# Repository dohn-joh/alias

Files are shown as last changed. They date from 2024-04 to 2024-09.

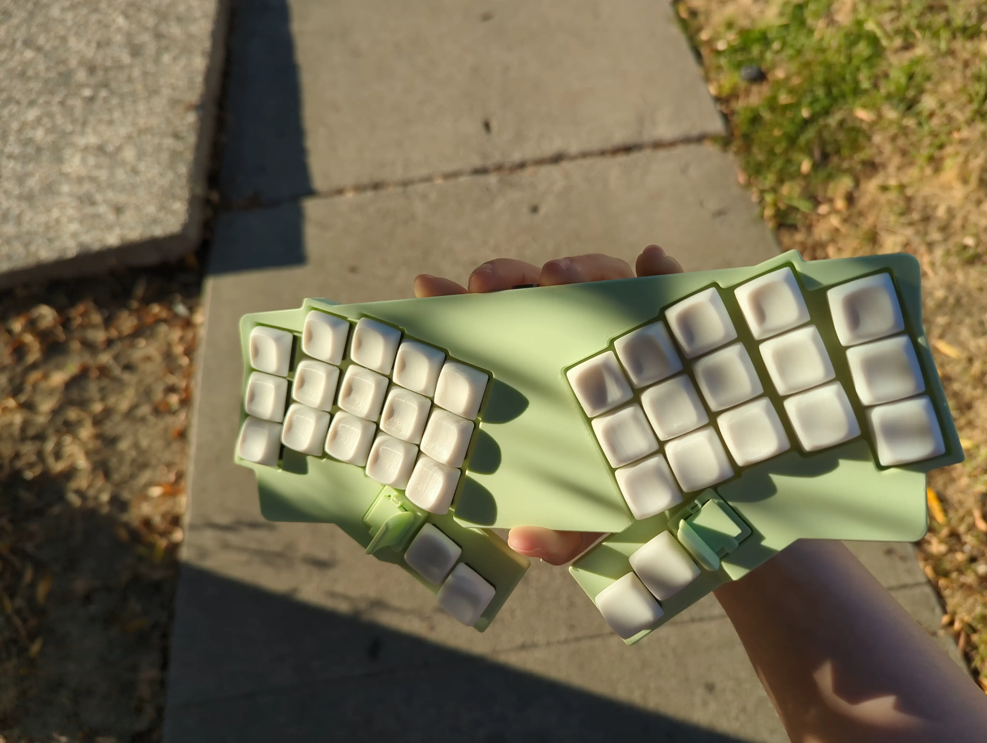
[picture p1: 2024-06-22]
photos/rotate.webp

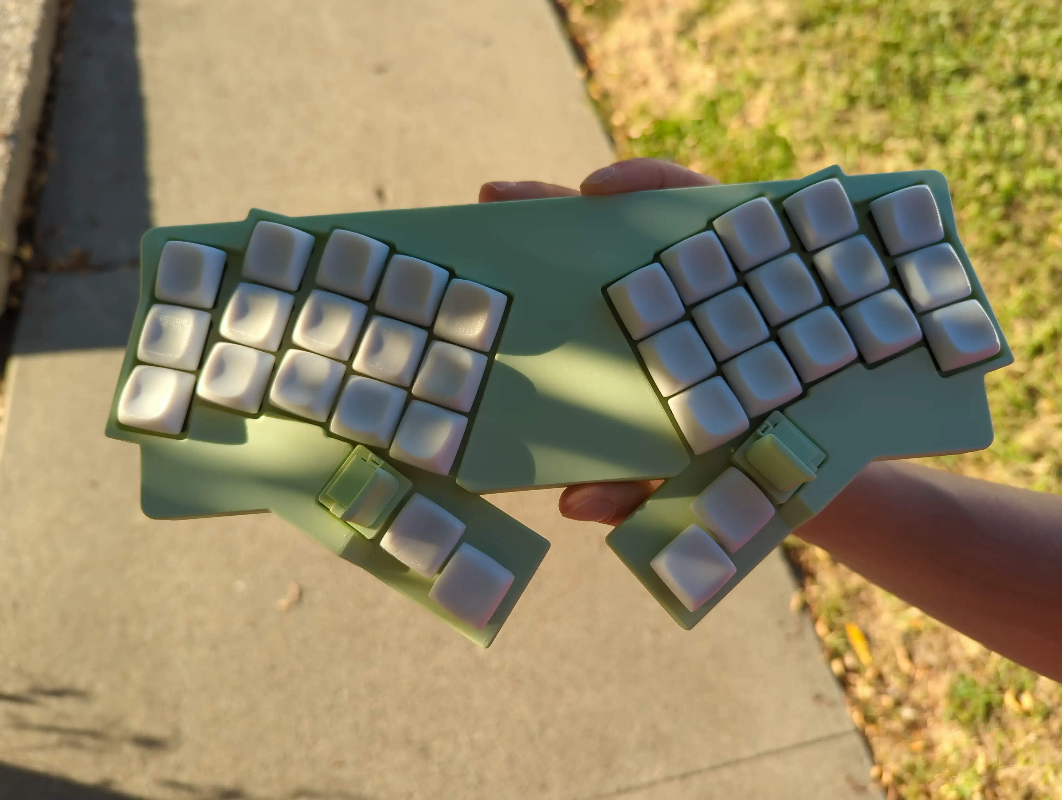
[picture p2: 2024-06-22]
photos/wave.webp

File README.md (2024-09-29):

# Alias

front
back
detail

## Features
- Custom 3D printed keycaps
  - [Lever keycaps](https://github.com/dohn-joh/keycaps)
  - [Low profile DES variant](https://github.com/dohn-joh/PseudoMakeMeKeyCapProfiles)
- Choc v1 and v2 compatible hotswap
- [Wireless dongle](https://github.com/dohn-joh/dongle-zmk)
- PCB generated in [ergogen](https://github.com/ergogen/ergogen)

## Compatibility/Disclaimer
Everything in this repo has been tested. Even so, use these files at your own risk. 
If you decide to have the pcb fabbed, 1.2mm pcb thickness is recommended. Higher thicknesses are still compatible but add height to the case.

- **Status of keycap compatibility**: only keycaps that are <=17.85mm wide and <=18mm deep are supported
- **Status of bottom case**: ~~cutouts are currently only compatible with choc v2 with the exception of the lever keys, which have cutouts that support both choc v1 and v2~~ fully compatible with both choc v1 and v2

## Parts
|Part: Model#|Link|
|-|-|
|Microcontroller: Supermini NRF52840 (or nice!nano)||
|Battery: 301230 with molex pico ezmate connector||
|Battery connector: molex pico ezmate 1x02||
|Power button: PCM12SMTR||
|Reset button: SKHLLCA010||
|Choc v1 or v2 switches x 36||
|Kailh Choc PG1350 Hot Swap Sockets x 36||
|Keycaps||
|Magnetic USB connector (optional): Netdot Gen10||

## Thanks
These people and many more helped make this keyboard possible. Yall are legends.
```
MrZealot
Pseudoku
petejohanson
caksoylar(bravekarma)
jcmkk3
ceoloide
infused-kim
Flatfootfox
sadekbaroudi
zzeneg
joelspadin
wolfwood
claussen
Geist
rmwphd(atinyzubat)
fish
Araxia
honorless
elkepenin
```

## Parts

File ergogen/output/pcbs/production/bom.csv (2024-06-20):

Designator | Footprint | Quantity | Value | LCSC Part #
CONN1 | conn_molex_pico_ezmate_1x02 | 1
D1, D10, D11, D12, D13, D14, D15, D16, D17, D18, D19, D2, D20, D21, D22, D23, D24, D25, D26, D27, D28, D29, D3, D30, D31, D32, D33, D34, D35, D36, D4, D5, D6, D7, D8, D9 | ComboDiode | 36
H1, H10, H11, H12, H13, H14, H15, H2, H3, H4, H5, H6, H7, H8, H9 | mounting_hole | 15
MCU1 | ProMicro | 1
PAD1 | pads | 1
S37 | SKHLLCA010 | 1 | SKHLLCA010
SW1 | power_switch | 1

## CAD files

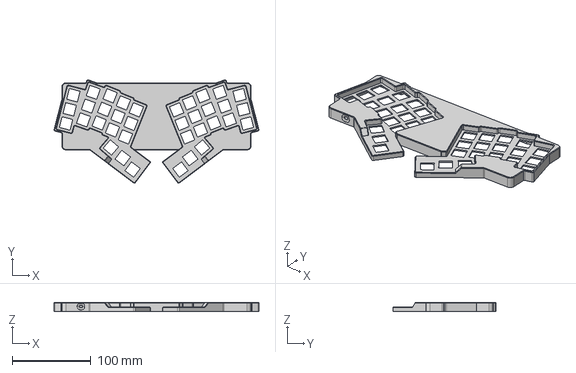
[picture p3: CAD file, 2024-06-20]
case/case_top.step
259.9 x 131.2 x 11.7 mm

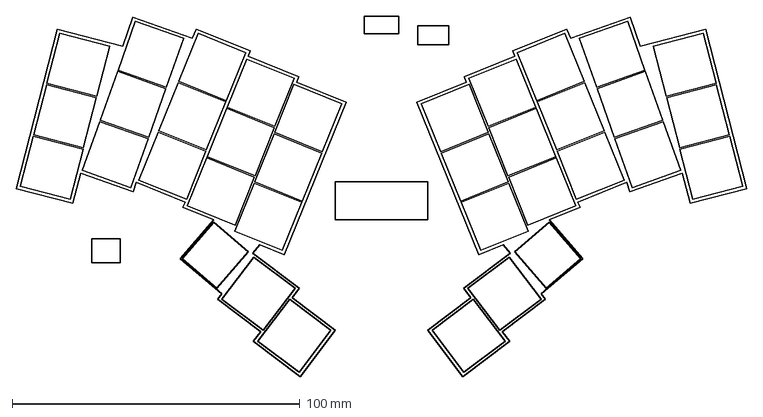
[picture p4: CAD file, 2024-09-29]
ergogen/output/outlines/preview.dxf
254.0 x 125.2 mm

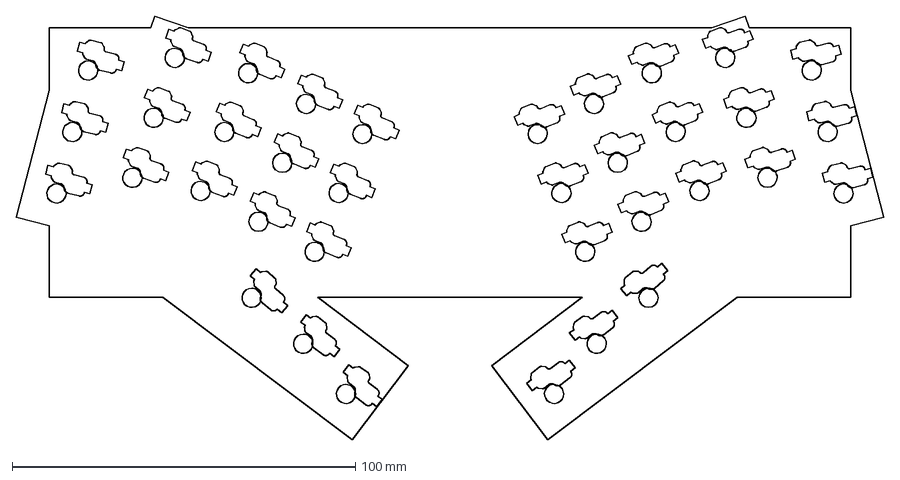
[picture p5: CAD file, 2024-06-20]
ergogen/output/pcbs/case_bottom-Edge_Cuts.dxf
252.6 x 123.5 mm

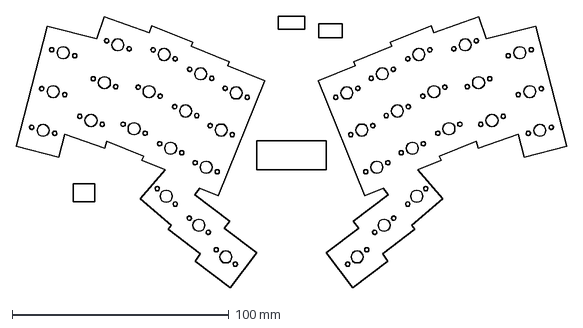
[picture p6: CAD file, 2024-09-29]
ergogen/output/outlines/case_bottom.dxf
254.0 x 125.2 mm

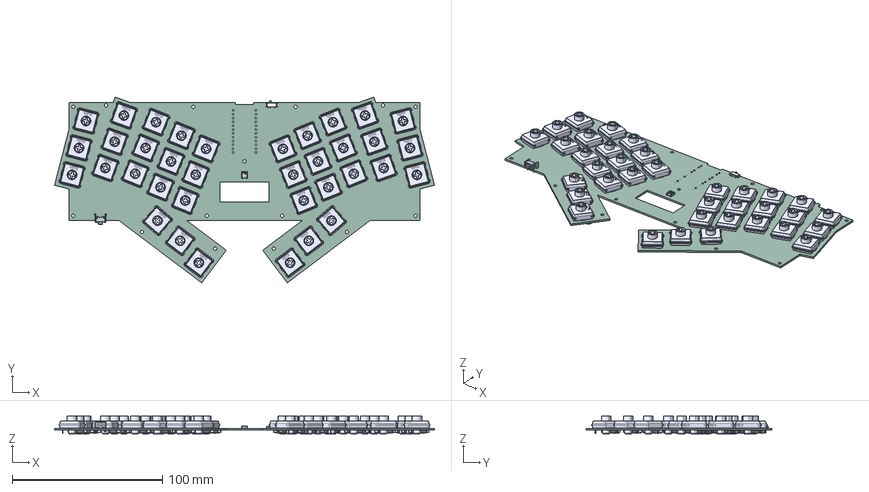
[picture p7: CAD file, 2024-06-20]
ergogen/output/pcbs/Alias.step
252.6 x 123.5 x 11.9 mm
781710002wbm000_01
PCM12SMTR
SKHLLC
Kailh_PG1352 x 36
PG1350 x 36
Alias_render_PCB

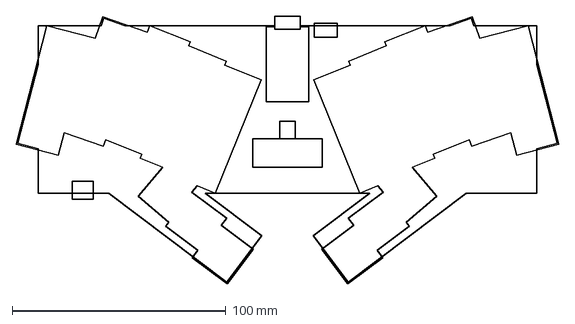
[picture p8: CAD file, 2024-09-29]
ergogen/output/outlines/pcb.dxf
254.0 x 125.2 mm

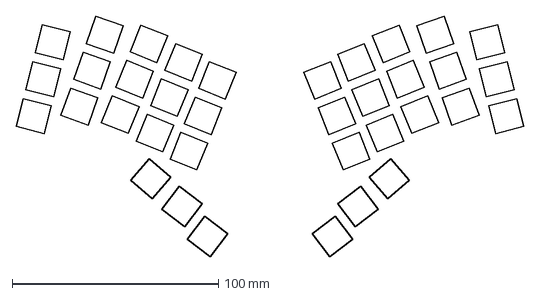
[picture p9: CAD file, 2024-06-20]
ergogen/output/outlines/switch_cutouts.dxf
246.3 x 116.6 mm

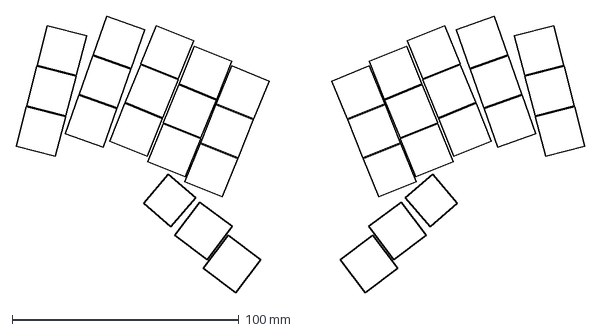
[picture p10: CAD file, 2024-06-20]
ergogen/output/outlines/keycaps.dxf
251.0 x 122.1 mm

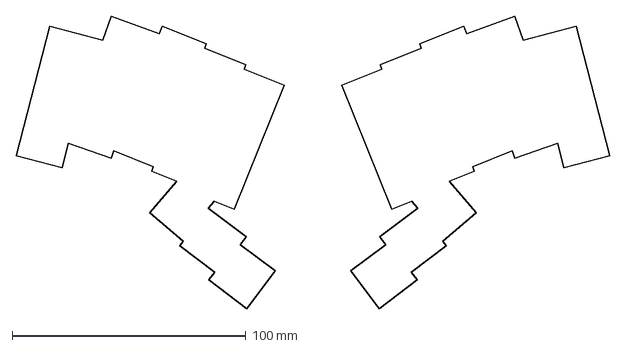
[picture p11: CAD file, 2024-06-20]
ergogen/output/outlines/key_walls.dxf
254.0 x 125.0 mm

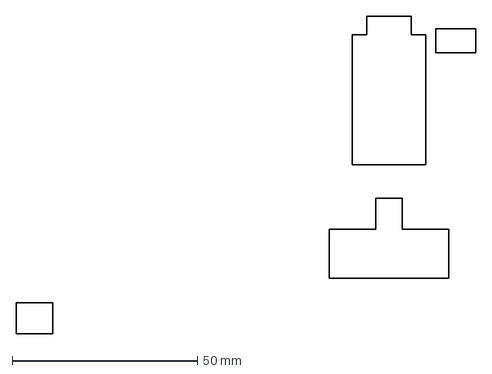
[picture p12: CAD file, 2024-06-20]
ergogen/output/outlines/case_cutouts.dxf
124.1 x 85.7 mm

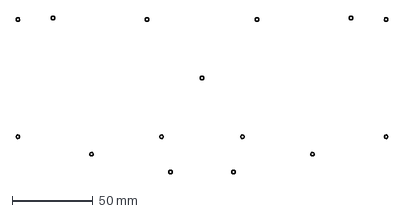
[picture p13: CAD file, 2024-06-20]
ergogen/output/outlines/screws.dxf
229.7 x 97.4 mm

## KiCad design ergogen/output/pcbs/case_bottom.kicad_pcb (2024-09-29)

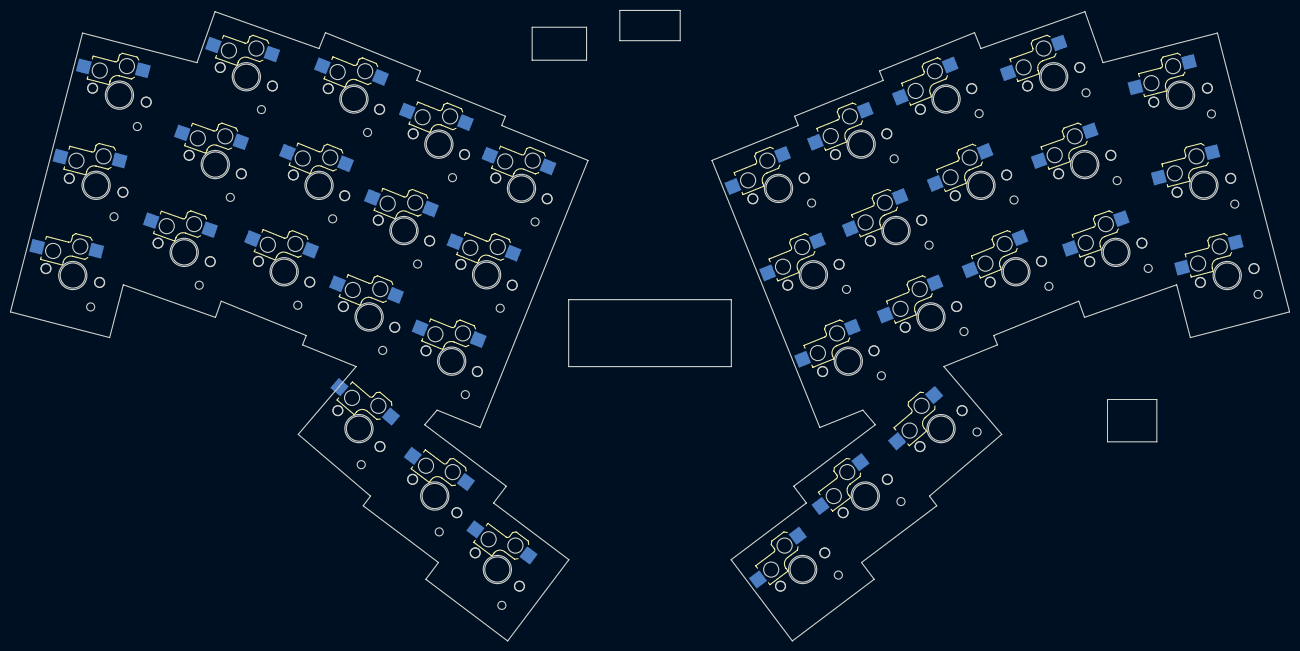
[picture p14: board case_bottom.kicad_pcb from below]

Board: 2 copper layers, 254.0 x 125.2 mm, 36 parts (36 on the bottom side), 5 nets, no tracks yet.

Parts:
S1, S2, S3, S4, S5, S6, S7, S8, S9, S10, S11, S12, S13, S14, S15, S16, S17, S18, S19, S20, S21, S22, S23, S24, S25, S26, S27, S28, S29, S30, S31, S32, S33, S34, S35, S36: switch_choc_v1_v2

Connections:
C0: S1.1, S2.1, S3.1, S16.1, S17.1, S18.1
C1: S4.1, S5.1, S6.1, S19.1, S20.1, S21.1
C2: S7.1, S8.1, S9.1, S22.1, S23.1, S24.1, S31.1, S34.1
C3: S10.1, S11.1, S12.1, S25.1, S26.1, S27.1, S32.1, S35.1
C4: S13.1, S14.1, S15.1, S28.1, S29.1, S30.1, S33.1, S36.1

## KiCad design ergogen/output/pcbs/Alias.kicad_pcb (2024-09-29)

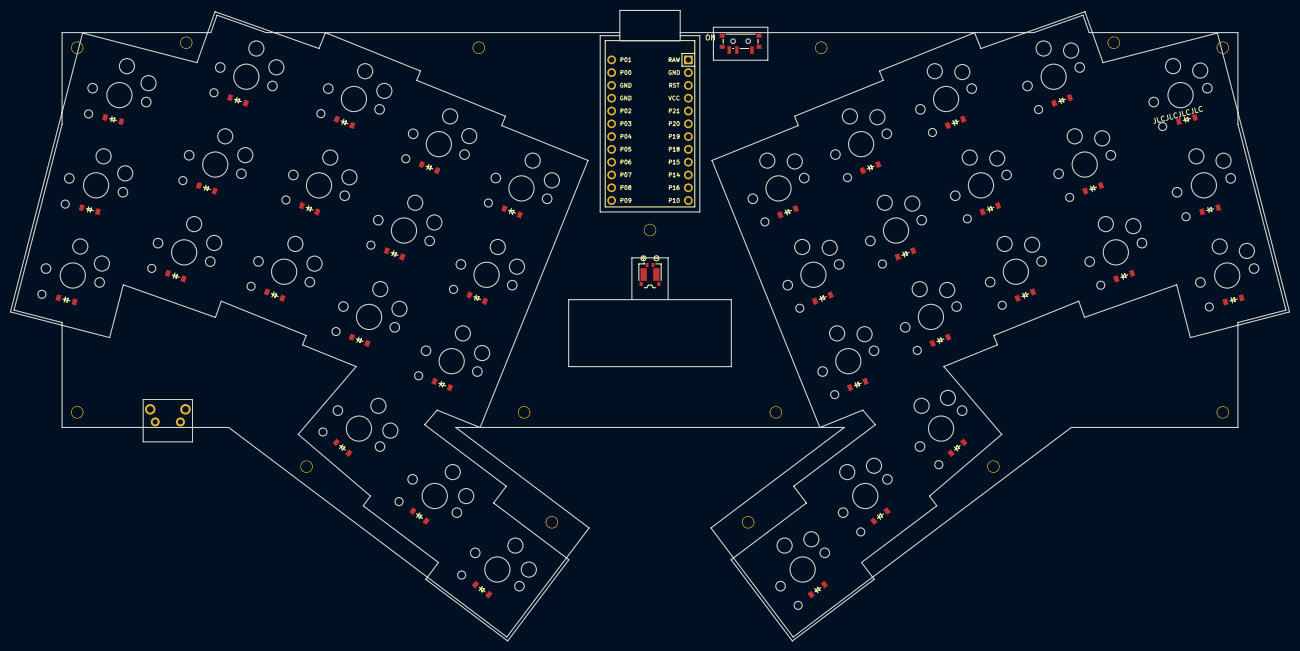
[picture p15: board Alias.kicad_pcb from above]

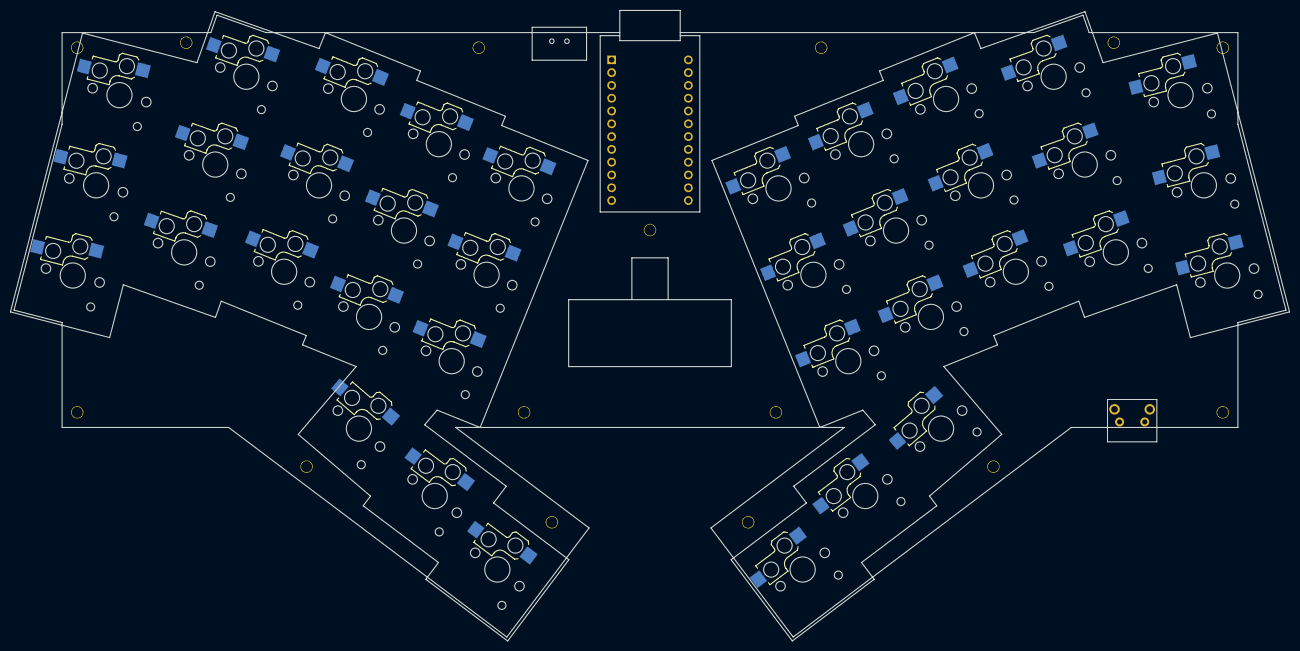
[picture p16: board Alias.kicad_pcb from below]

Board: 2 copper layers, 254.0 x 125.2 mm, 93 parts (36 on the bottom side), 53 nets, no tracks yet.

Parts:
CONN1: conn_molex_pico_ezmate_1x02
D1, D2, D3, D4, D5, D6, D7, D8, D9, D10, D11, D12, D13, D14, D15, D16, D17, D18, D19, D20, D21, D22, D23, D24, D25, D26, D27, D28, D29, D30, D31, D32, D33, D34, D35, D36: ComboDiode
H1, H2, H3, H4, H5, H6, H7, H8, H9, H10, H11, H12, H13, H14, H15: mounting_hole
ICON1: icon_bat
MCU1: ProMicro
PAD1: pads
S1, S2, S3, S4, S5, S6, S7, S8, S9, S10, S11, S12, S13, S14, S15, S16, S17, S18, S19, S20, S21, S22, S23, S24, S25, S26, S27, S28, S29, S30, S31, S32, S33, S34, S35, S36: switch_choc_v1_v2
S37: SKHLLCA010
SW1: power_switch

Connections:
BAT_P: CONN1.1, PAD1.1, SW1.3
C0: MCU1.17, S1.1, S2.1, S3.1, S16.1, S17.1, S18.1
C1: MCU1.18, S4.1, S5.1, S6.1, S19.1, S20.1, S21.1
C2: MCU1.19, S7.1, S8.1, S9.1, S22.1, S23.1, S24.1, S31.1, S34.1
C3: MCU1.20, S10.1, S11.1, S12.1, S25.1, S26.1, S27.1, S32.1, S35.1
C4: MCU1.21, S13.1, S14.1, S15.1, S28.1, S29.1, S30.1, S33.1, S36.1
GND: CONN1.2, MCU1.2, MCU1.15, MCU1.16, PAD1.2, S37.2
R0: D3.1, D6.1, D9.1, D12.1, D15.1, MCU1.5
R1: D2.1, D5.1, D8.1, D11.1, D14.1, MCU1.6
R2: D1.1, D4.1, D7.1, D10.1, D13.1, MCU1.7
R3: D31.1, D32.1, D33.1, MCU1.8
R4: D18.1, D21.1, D24.1, D27.1, D30.1, MCU1.9
R5: D17.1, D20.1, D23.1, D26.1, D29.1, MCU1.10
R6: D16.1, D19.1, D22.1, D25.1, D28.1, MCU1.11
R7: D34.1, D35.1, D36.1, MCU1.12
RAW: MCU1.1, SW1.2
RST: MCU1.3, S37.1
base_cluster: D32.2, S32.2
extension_cluster: D33.2, S33.2
flexion_cluster: D31.2, S31.2
index_bottom: D10.2, S10.2
index_home: D11.2, S11.2
index_top: D12.2, S12.2
inner_bottom: D13.2, S13.2
inner_home: D14.2, S14.2
inner_top: D15.2, S15.2
middle_bottom: D7.2, S7.2
middle_home: D8.2, S8.2
middle_top: D9.2, S9.2
mirror_base_cluster: D35.2, S35.2
mirror_extension_cluster: D36.2, S36.2
mirror_flexion_cluster: D34.2, S34.2
mirror_index_bottom: D25.2, S25.2
mirror_index_home: D26.2, S26.2
mirror_index_top: D27.2, S27.2
mirror_inner_bottom: D28.2, S28.2
mirror_inner_home: D29.2, S29.2
mirror_inner_top: D30.2, S30.2
mirror_middle_bottom: D22.2, S22.2
mirror_middle_home: D23.2, S23.2
mirror_middle_top: D24.2, S24.2
mirror_pinky_bottom: D16.2, S16.2
mirror_pinky_home: D17.2, S17.2
mirror_pinky_top: D18.2, S18.2
mirror_ring_bottom: D19.2, S19.2
mirror_ring_home: D20.2, S20.2
mirror_ring_top: D21.2, S21.2
pinky_bottom: D1.2, S1.2
pinky_home: D2.2, S2.2
pinky_top: D3.2, S3.2
ring_bottom: D4.2, S4.2
ring_home: D5.2, S5.2
ring_top: D6.2, S6.2

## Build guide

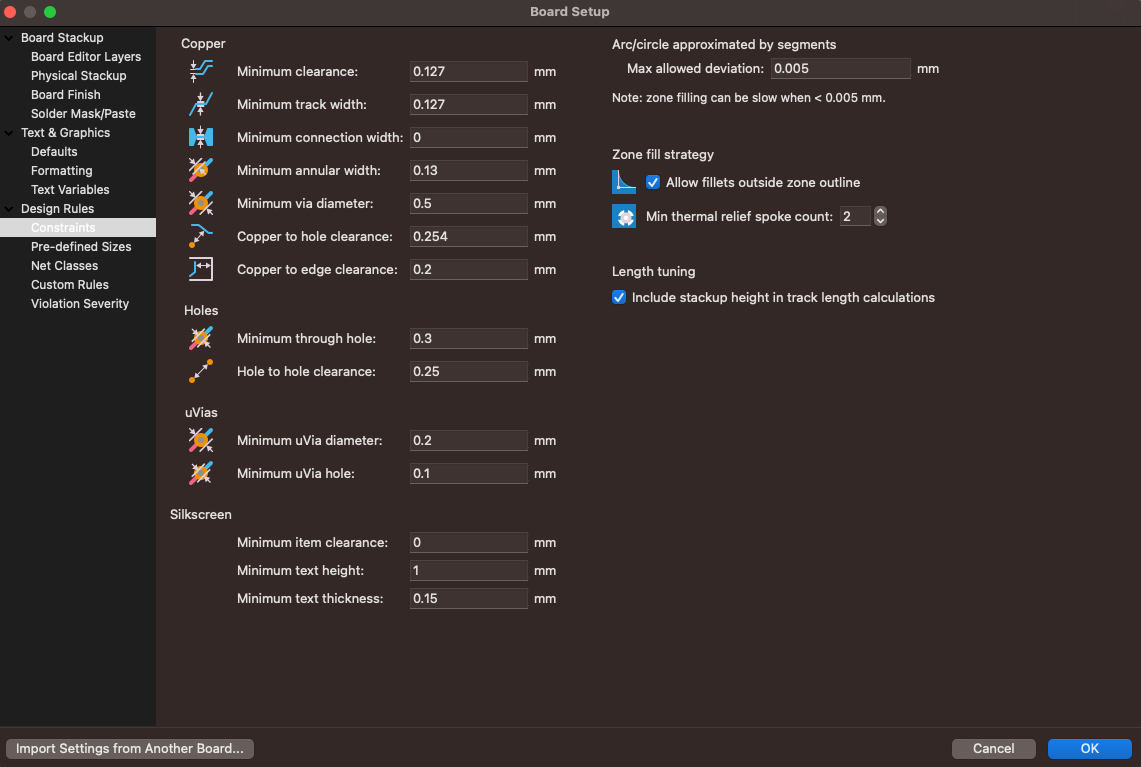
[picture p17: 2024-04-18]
ergogen/jlc_setup.png

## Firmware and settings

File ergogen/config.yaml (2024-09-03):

presets:
  mx_min_spaced:
    capx: 15.5
    capy: 15.5
    capthumbx: 17.8
    capthumby: 16.5
    kx: 18 # jcmkk3 uses 16.5. 18 for choc x spacing
    ky: 16.5
    kcx: kx # spacing for custom thumb keycaps
    kcy: ky # spacing for custom thumb keycaps
    inner_spread: 0.9kx
    pinky_splay: 5
    ring_splay: 3
    thumb_offsetx: 0.75kx
    switch_xy: 14

  mx_spaced: # y -0.5mm
    capx: 17.85
    capy: 18
    capthumbx: 17.95
    capthumby: 18.35
    capleverx: 15.85
    caplevery: 16.8
    kx: 19
    ky: 18.5
    inner_spread: kx-0.5
    pinky_splay: 5
    ring_splay: 2.5
    thumb_offsetx: 0.25kx
    switch_xy_mx: 14 # switch hole
    switch_xy_choc: 13.8

units:
  $extends: presets.mx_spaced
  angle: 22 # was 27.5
  sf: 19.151 # may want to change this for fab
  ## nice!nano dimensions (from Nicell himself)
  # mcux: 18
  # mcuy: 33.4
  ## supermini dimensions
  # mcux: 18.1 # with 0.1mm tolerance for fr4 variance
  # mcuy: 33.85 # length from usb to end of pcb
  ## promicro footprint dimensions
  mcux: 17.78
  mcuy: 33.02 # board only, no usb
  # netdot usb adapter dimensions
  ndx: 12 # actual is ~10.82 at widest section
  ndy: 6 # actual is 5.4 while plugged in
  # space between keycap and case wall
  wallx: 1.25
  wally: 1.1

  # joycon battery dimensions plus tolerance
  # bcx: 24.5+0.7
  # bcy: 52+0.7

  # 301230 battery dimensions
  bcx: 31.5+0.8
  bcy: 12.5+0.8

  # screw hole diameter (M2)
  scd: 2.2
  # screw head diameter ~3.3

points:
  zones:
    matrix:
      anchor:
        # Fix placement on KiCAD sheet.
        shift: [100, -100]
        rotate: -angle + pinky_splay + ring_splay
      key:
        width: capx
        height: capy
        padding: ky
        spread: kx
        autobind: 0
      mirror:
        ref: matrix_inner_top
        shift: [0.5kx,0.5ky]
        distance: 26.5
      columns:
        pinky:
          rows:
            top:
              bind: [0, 0.5kx, 0.5ky, 0]
            home:
              bind: [0.5ky, 0.5kx, 0, 0]
            bottom:
              bind: [0.5ky, 0, 0, 0]
          key:
            column_net: C0
        ring:
          rows:
            top:
              bind: [0, 0.5kx, 0.5ky, 0]
            home:
              bind: [0.5ky, 0.5kx, 0, 0]
            bottom:
              bind: [0.5ky, 0, 0, 0.5kx]
          key:
            column_net: C1
            stagger: 10 # was 10
            spread: kx+1
            splay: -pinky_splay
            origin: [0, -3]
        middle:
          rows:
            home:
              bind: [0.5ky, 0.5kx, 0, 0]
            bottom:
              bind: [0.5ky, 0.5kx, 0, 0.5kx]
          key:
            column_net: C2
            stagger: 3 # was 2
            spread: kx+1
            splay: -ring_splay
        index:
          rows:
            top:
              bind: [0, 0, 0, 0.5kx]
            home:
              bind: [0.5ky, 0.5kx, 0, 0]
            bottom:
              bind: [0.5ky, 0.5kx, 0, 0]
          key:
            column_net: C3
            stagger: -2
        inner:
          rows:
            top:
              bind: [0, 0, 0, 0.5kx]
            home:
              bind: [0.5ky, 0, 0, 0]
            bottom:
              bind: [0.5ky, 0, 0, 0]
            bottom.mirror:
              bind: [0.5ky, 0, 0, 0]
          key:
            column_net: C4
            spread: inner_spread
            stagger: -2
      rows:
        bottom:
          row_net: R2
        bottom.mirror:
          row_net: R6
        home:
          row_net: R1
        home.mirror:
          row_net: R5
        top:
          row_net: R0
        top.mirror:
          row_net: R4
    thumb:
      anchor:
        ref: matrix_index_bottom
        shift: [thumb_offsetx-4.82+3, -30.1+3]
      key:
        width: capx
        height: capy
        padding: ky
        spread: kx+0.7
        autobind: 0
      mirror.$extends: points.zones.matrix.mirror
      columns:
        flexion:
          rows:
            cluster:
              bind: [0.5ky, 0, 0, 0]
          key:
            splay: -20
            orient: 47.5
            shift: [152.1536-148.8676+2.5, -(139.4486-142.9557)] # x was +1.6
            rotate: -46
            column_net: C2
        base:
          rows:
            cluster:
              bind: [0, 0.12kx, 0, 0.2kx]
          key:
            splay: 5
            stagger: 2.5+4
            spread: cx+2.5
            column_net: C3
            adjust:
              orient: angle - pinky_splay - ring_splay + 20 + 3
              shift: [0.887, -0.4617]
              rotate: -angle + pinky_splay + ring_splay - 20 - 3
        extension:
          rows:
            cluster:
              bind: [5.976+2, 0, 0, 38.659+1.5+15]
          key:
            column_net: C4
            stagger: -4
      rows:
        cluster:
          row_net: R3
        cluster.mirror:
          row_net: R7
    ref_top_center:
      anchor:
        aggregate.parts: [matrix_middle_top, mirror_matrix_middle_top]
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

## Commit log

2024-06-20 update everything
    [Alias.kicad_pcb, Alias.step, Alias_manually_routed.kicad_pcb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]
2024-09-03 update case compatibility
    [Alias.kicad_pcb, case_bottom.dxf, case_bottom.kicad_pcb]
